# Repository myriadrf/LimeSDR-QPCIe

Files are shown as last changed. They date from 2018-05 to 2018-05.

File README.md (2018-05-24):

# LimeSDR-QPCIe 

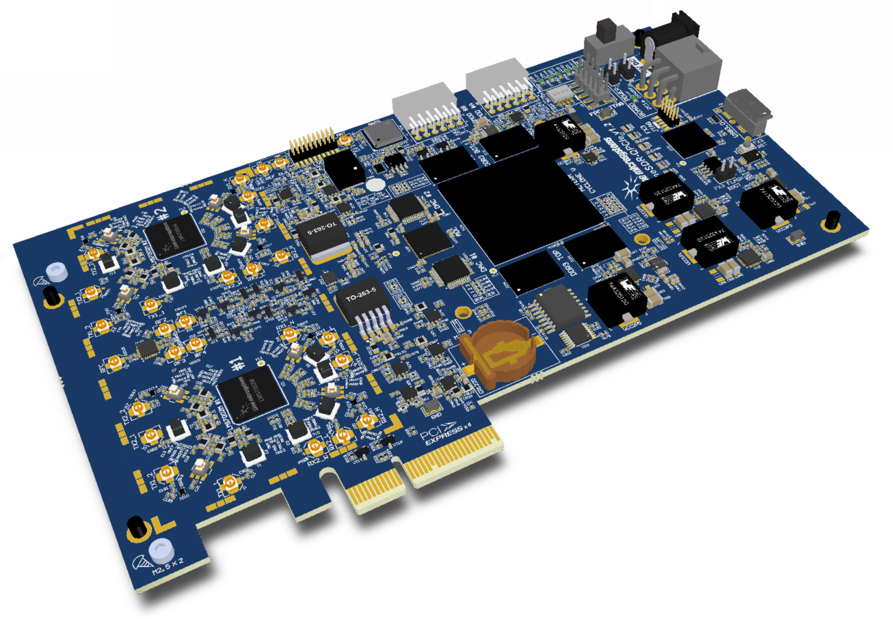
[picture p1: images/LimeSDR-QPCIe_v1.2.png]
LimeSDR-Mini board


The [LimeSDR-QPCIe ](https://wiki.myriadrf.org/LimeSDR-QPCIe) board provides a hardware platform for developing and prototyping high-performance and logic-intensive digital and RF designs using Intel’s Cyclone V FPGA and Lime Microsystems transceivers.

* **FPGA Features**
  * Cyclone V, 5CGXFC7D7F31C8N device in 896-pin FBGA package
  * 150’000 logic elements
  * 6860 Kbits embedded memory
  * 312 embedded 18x18 multipliers 
  * 7 PLLs 
  * 9 Transceivers (2.5Gbps)
  * PCIe Hard IP Blocks
  * 2 Hard Memory Controllers
 
* **RF**
  * 2x LMS7002M, FPRF transceivers
  * Onboard RSSI measurement circuits
  * Onboard loopback control switches

* **DACs and ADCs**
  * 2x DAC5672A, dual, 14-bit, Digital-To-Analog converters
  * 1x ADS424, Dual-Channel, 14-bit, Analog-To-Digital converter

* **Memory Devices**
  * 4 x 2Gbit DDR3 SDRAM (128M x 16)
  * 4Mbit flash for FX3 firmware
  * 128Mbit flash for FPGA gateware
  * 2 x 128Kbit and 2 x 512Kbit EEPROMs for LMS MCU firmware, LMS MCU data
  * 1 x 128K EEPROM for FX3 or FPGA data

* **Connections**
  * microUSB3.0 (type B) connector
  * PCIe edge connector
  * Coaxial RF (U.FL) connectors
  * 2x PMOD header (0.1” pitch)
  * FPGA (0.1” pitch) and FX3 (0.05” pitch) JTAG connectors 
  * 12V DC power jack and pinheader
  * LVDS connector (0.05” pitch)
  * Fan connector (12V/5V)
  * PCIe 6-pin power connector
  * Holder for coin cell CR1220 battery

* **Clock System**
  * 30.72MHz VCTCXO (precision: ±1 ppm initial, ±4 ppm stable).
  * Possibility to lock VCTCXO to external clock using ADF4002 or tune VCTCXO by onboard DAC (AD5662)
  * Programmable clock generator for the FPGA reference clock input or LMS PLLs
  * VCTCXO clock output for external device synchronization.
  * 1x 100 MHz, 4 x 125MHz crystal oscillators for FPGA

* **Miscellaneous devices**
  * LM75 Digital temperature sensor with 2-Wire Interface.
  * DS3231 real-time clock.
  * M0578-A3 GPS/GNSS module receiver

* **Board Size 190mm x 106.7mm (7.48” x 4.20”)**

## Contents

The directory structure is as follows:

      hardware/<version>/
          Libraries/             - Component Libraries
          OutputJobs/            - Output jobs
          PCB/                   - PCB design
          Project Outputs/       - BOM, rule check reports, Gerbers, pick & place files, PDFs
          Schematics/            - Schematic diagrams

## Licensing

The hardware designs are licensed under a Creative Commons Attribution 3.0 Unported licence.

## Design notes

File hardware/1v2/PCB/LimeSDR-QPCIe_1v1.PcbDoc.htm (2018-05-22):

Reporting Options

# File in Newer Format

Date | : | 2016-11-18
Time | : | 12:06:40
Filename | : | E:\Saniok\Lime Micro\Lime PCBs\LimeSDR-QPCIe_1v0\AltiumDesigner Design files\PCB\LimeSDR-QPCIe_1v1.PcbDoc

Version | Warning
Release 17.0 | CAUTION - Component parameters added.
Release 17.0 | CAUTION - Supports of backdrilling

This file was generated by a later version of the software

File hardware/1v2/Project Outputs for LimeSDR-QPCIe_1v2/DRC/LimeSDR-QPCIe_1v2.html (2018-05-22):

Altium

# Design Rule Verification Report

Date: | | 2017-09-22
Time: | | 15:32:23
Elapsed Time: | | 00:11:34
Filename: | | E:\Saniok\Lime Micro\Lime PCBs\LimeSDR-QPCIe_1v2\AltiumDesigner Design files\PCB\LimeSDR-QPCIe_1v2.PcbDoc

Warnings: | | 15
Rule Violations: | | 0

## Summary

Warnings | Count
Unplated multi-layer pad(s) detected | 15
Total | 15

Rule Violations | Count
Matched Lengths(Tolerance=0.1mm) (InNetClass('RxPLL_CLK')) | 0
Matched Lengths(Tolerance=0.1mm) (InNetClass('TxPLL_CLK')) | 0
Width Constraint (Min=0.1mm) (Max=20mm) (Preferred=0.2mm) (All) | 0
Short-Circuit Constraint (Allowed=Yes) (InComponent('IC50') and ispad and (name='IC50-4')),(All) | 0
Component Clearance Constraint ( Horizontal Gap = -1mm, Vertical Gap = Infinite ) (InComponent('IC30')),(InComponent('IC32')) | 0
Differential Pairs Uncoupled Length using the Gap Constraints (Min=0.1mm) (Max=0.3mm) (Prefered=0.14mm) and Width Constraints (Min=0.1mm) (Max=0.5mm) (Prefered=0.2mm) (InNetClass('TX1_BB_I') or InNetClass('TX1_BB_Q')) | 0
Matched Lengths(Tolerance=0.8mm) (InNetClass('FX3_GPIF1')) | 0
Matched Lengths(Tolerance=0.8mm) (InNetClass('FX3_CTL[0..12]') or InNetClass('FX3_DQ[0..15]') or InNet('FX3_PCLK')) | 0
Matched Lengths(Tolerance=0.5mm) (InNetClass('DAC2_DATA')) | 0
Differential Pairs Uncoupled Length using the Gap Constraints (Min=0.1mm) (Max=0.3mm) (Prefered=0.2mm) and Width Constraints (Min=0.1mm) (Max=0.3mm) (Prefered=0.2mm) (InNetClass('RX_RF')) | 0
Differential Pairs Uncoupled Length using the Gap Constraints (Min=0.1mm) (Max=0.3mm) (Prefered=0.2mm) and Width Constraints (Min=0.1mm) (Max=0.3mm) (Prefered=0.2mm) (InNetClass('TX_RF')) | 0
Differential Pairs Uncoupled Length using the Gap Constraints (Min=0.1mm) (Max=0.3mm) (Prefered=0.1mm) and Width Constraints (Min=0.2mm) (Max=0.2mm) (Prefered=0.2mm) (InNetClass('FX3_DATA')) | 0
Matched Lengths(Tolerance=0.5mm) (InNetClass('LMS1_PORT2')) | 0
Matched Lengths(Tolerance=0.5mm) (InNetClass('LMS1_PORT1')) | 0
Differential Pairs Uncoupled Length using the Gap Constraints (Min=0.1mm) (Max=0.2mm) (Prefered=0.1mm) and Width Constraints (Min=0.1mm) (Max=0.5mm) (Prefered=0.1mm) (InNetClass('DDR2_1_CK') or InNetClass('DDR2_1_CK')) | 0
Modified Polygon (Allow modified: No), (Allow shelved: No) | 0
Height Constraint (Min=0mm) (Max=2.67mm) (Prefered=2.67mm) (OnBottomLayer) | 0
Component Clearance Constraint ( Horizontal Gap = 0.01mm, Vertical Gap = 0.254mm ) (All),(All) | 0
Differential Pairs Uncoupled Length using the Gap Constraints (Min=0.1mm) (Max=0.3mm) (Prefered=0.1mm) and Width Constraints (Min=0.1mm) (Max=0.6mm) (Prefered=0.2mm) (All) | 0
Height Constraint (Min=0mm) (Max=14.47mm) (Prefered=14.47mm) (OnTopLayer) | 0
Hole Size Constraint (Min=0.2mm) (Max=10mm) (All) | 0
Pads and Vias to follow the Drill pairs settings | 0
Routing Via (MinHoleWidth=0.2mm) (MaxHoleWidth=4.5mm) (PreferredHoleWidth=0.2mm) (MinWidth=0.31mm) (MaxWidth=5mm) (PreferedWidth=0.4mm) (All) | 0
Width Constraint (Min=0.1mm) (Max=5mm) (Preferred=0.2mm) (All) | 0
Power Plane Connect Rule(Relief Connect )(Expansion=0.508mm) (Conductor Width=0.254mm) (Air Gap=0.254mm) (Entries=4) (All) | 0
Un-Routed Net Constraint ( (All) ) | 0
Short-Circuit Constraint (Allowed=No) (All),(All) | 0
Clearance Constraint (Gap=0.1mm) (All),(All) | 0
Routing Layers(All) | 0
Hole To Hole Clearance (Gap=0.15mm) (All),(All) | 0
Net Antennae (Tolerance=0mm) (All) | 0
Matched Lengths(Tolerance=0.5mm) (InNetClass('DDR3_TOP_DQ[0..31]')) | 0
Matched Lengths(Tolerance=0.5mm) (InNetClass('DDR2_2_A[0..12]')) | 0
Matched Lengths(Tolerance=0.5mm) (InNetClass('DDR3_BOT_DQ[0..31]')) | 0
Matched Lengths(Tolerance=0.5mm) (InNetClass('DDR2_1_A[0..12]')) | 0
Differential Pairs Uncoupled Length using the Gap Constraints (Min=0.1mm) (Max=0.2mm) (Prefered=0.1mm) and Width Constraints (Min=0.1mm) (Max=0.4mm) (Prefered=0.1mm) (InNet('FX3_XTAL_N') or InNet('FX3_XTAL_P')) | 0
Matched Lengths(Tolerance=0.5mm) (InNetClass('DDR3_TOP_A[0..13]')) | 0
Matched Lengths(Tolerance=0.5mm) (InNetClass('DDR3_BOT_A[0..13]')) | 0
Differential Pairs Uncoupled Length using the Gap Constraints (Min=0.2mm) (Max=0.2mm) (Prefered=0.2mm) and Width Constraints (Min=0.2mm) (Max=0.5mm) (Prefered=0.3mm) (InNetClass('PCIE') and (OnTopLayer or OnBottomLayer)) | 0
Matched Lengths(Tolerance=0.5mm) (InNetClass('DAC1_DATA')) | 0
Matched Lengths(Tolerance=0.5mm) (InNetClass('LMS2_PORT1')) | 0
Matched Lengths(Tolerance=0.5mm) (InNetClass('LMS2_PORT2')) | 0
Component Clearance Constraint ( Horizontal Gap = -1mm, Vertical Gap = Infinite ) (InComponent('R372') or InComponent('R374') or InComponent('R368') or InComponent('R364') or InComponent('R379') or InComponent('R384')),(InComponent('R372') or InComponent('R374') or InComponent('R368') or InComponent('R364') or InComponent('R379') or InComponent('R384')) | 0
Height Constraint (Min=0mm) (Max=30mm) (Prefered=14.47mm) (InComponent('FAN1') or HasFootprint('PCIe_bracket')) | 0
Component Clearance Constraint ( Horizontal Gap = -1mm, Vertical Gap = Infinite ) (HasFootprint('PCIE_BRACKET')),(HasFootprint('PCIe_bracket_screw_M2.5')) | 0
Total | 0

## Warnings

Unplated multi-layer pad(s) detected

Pad Free-0(121.375mm,111.175mm) on MultiLayer on Net GND

Pad Free-0(123.775mm,111.175mm) on MultiLayer on Net GND

Pad Free-0(122.575mm,111.175mm) on MultiLayer on Net GND

Pad Free-0(93.35mm,12.8mm) on MultiLayer on Net GND

Pad Free-0(94.55mm,12.8mm) on MultiLayer on Net GND

Pad Free-0(95.75mm,12.8mm) on MultiLayer on Net GND

Pad Free-0(190.025mm,60.825mm) on MultiLayer on Net GND

Pad Free-0(190.025mm,63.225mm) on MultiLayer on Net GND

Pad Free-0(190.025mm,62.025mm) on MultiLayer on Net GND

Pad Free-0(43.975mm,111.2mm) on MultiLayer on Net GND

Pad Free-0(46.375mm,111.2mm) on MultiLayer on Net GND

Pad Free-0(45.175mm,111.2mm) on MultiLayer on Net GND

Pad Free-0(0.05mm,63.175mm) on MultiLayer on Net GND

Pad Free-0(0.05mm,60.775mm) on MultiLayer on Net GND

Pad Free-0(0.05mm,61.975mm) on MultiLayer on Net GND

Back to top

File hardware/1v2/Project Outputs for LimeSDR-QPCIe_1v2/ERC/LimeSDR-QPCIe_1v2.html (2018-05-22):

Altium

# Electrical Rule Check Report

Date: | | 2017-09-22
Time: | | 15:44:22
Filename: | | E:\Saniok\Lime Micro\Lime PCBs\LimeSDR-QPCIe_1v2\AltiumDesigner Design files\Project Outputs for LimeSDR-QPCIe_1v2\ERC\LimeSDR-QPCIe_1v2.html

Class | Document | Message
Warning | 25_Clocks_1.SchDoc | CLK_LMK_FPGA_IN contains IO Pin and Output Pin objects (Pin IC29-AB17)
Warning | 10_RSSI1.SchDoc | FPGA_SPI2_LMS1_RX1_I_MISO contains IO Pin and Output Pin objects (Pin IC29-J7)
Warning | 10_RSSI1.SchDoc | FPGA_SPI2_LMS1_RX1_Q_MISO contains IO Pin and Output Pin objects (Pin IC29-A3)
Warning | 11_RSSI2.SchDoc | FPGA_SPI2_LMS2_RX1_I_MISO contains IO Pin and Output Pin objects (Pin IC29-H15)
Warning | 11_RSSI2.SchDoc | FPGA_SPI2_LMS2_RX1_Q_MISO contains IO Pin and Output Pin objects (Pin IC29-G9)
Warning | 11_RSSI2.SchDoc | FPGA_SPI2_LMS2_RX2_I_MISO contains IO Pin and Output Pin objects (Pin IC29-C27)
Warning | 11_RSSI2.SchDoc | FPGA_SPI2_LMS2_RX2_Q_MISO contains IO Pin and Output Pin objects (Pin IC29-F6)
Warning | 20_ADC.SchDoc | Net ADC_CLKC_N has no driving source (Pin C639-1,Pin IC37-26)
Warning | 20_ADC.SchDoc | Net ADC_CLKC_P has no driving source (Pin C638-1,Pin IC37-25)
Warning | 20_ADC.SchDoc | Net ADC_CTRL1 has no driving source (Pin IC37-35,Pin R238-1,Pin R239-2)
Warning | 20_ADC.SchDoc | Net ADC_CTRL2 has no driving source (Pin IC37-36,Pin R240-1,Pin R241-2)
Warning | 20_ADC.SchDoc | Net ADC_CTRL3 has no driving source (Pin IC37-37,Pin R242-1,Pin R243-2)
Warning | 20_ADC.SchDoc | Net ADC_INA_N has no driving source (Pin IC37-30,Pin R226-1,Pin R230-1)
Warning | 20_ADC.SchDoc | Net ADC_INA_P has no driving source (Pin IC37-29,Pin R231-1,Pin R233-1)
Warning | 20_ADC.SchDoc | Net ADC_INB_N has no driving source (Pin IC37-20,Pin R211-1,Pin R215-1)
Warning | 20_ADC.SchDoc | Net ADC_INB_P has no driving source (Pin IC37-19,Pin R216-1,Pin R218-1)
Warning | 10_RSSI1.SchDoc | Net ADL1_ADJA has no driving source (Pin IC19-21,Pin R99-1,Pin R106-1)
Warning | 10_RSSI1.SchDoc | Net ADL1_ADJB has no driving source (Pin IC19-4,Pin R98-1,Pin R105-2)
Warning | 11_RSSI2.SchDoc | Net ADL2_ADJA has no driving source (Pin IC24-21,Pin R124-1,Pin R131-1)
Warning | 11_RSSI2.SchDoc | Net ADL2_ADJB has no driving source (Pin IC24-4,Pin R123-1,Pin R130-2)
Warning | 11_RSSI2.SchDoc | Net ADL3_ADJA has no driving source (Pin IC27-21,Pin R144-1,Pin R152-1)
Warning | 11_RSSI2.SchDoc | Net ADL3_ADJB has no driving source (Pin IC27-4,Pin R143-1,Pin R151-2)
Warning | 15_FPGA_misc_banks.SchDoc | Net CLK125_FPGA_REFC_N has no driving source (Pin C326-1,Pin IC29-R7)
Warning | 15_FPGA_misc_banks.SchDoc | Net CLK125_FPGA_REFC_P has no driving source (Pin C325-1,Pin IC29-R8)
Warning | 21_DAC.SchDoc | Net DAC1_CLK has no driving source (Pin IC40-17,Pin IC40-18,Pin IC40-19,Pin IC40-20,Pin IC55-3,Pin R254-2)
Warning | 21_DAC.SchDoc | Net DAC2_CLK has no driving source (Pin IC41-17,Pin IC41-18,Pin IC41-19,Pin IC41-20,Pin IC55-5,Pin R256-2)
Warning | 15_FPGA_misc_banks.SchDoc | Net EXT_GXB_CLK_IC_N has no driving source (Pin IC29-N7,Pin R184-1)
Warning | 15_FPGA_misc_banks.SchDoc | Net EXT_GXB_CLK_IC_P has no driving source (Pin IC29-P8,Pin R183-1)
Warning | 15_FPGA_misc_banks.SchDoc | Net EXT_GXB_RX6_IC_N has no driving source (Pin IC29-R1,Pin R186-1)
Warning | 15_FPGA_misc_banks.SchDoc | Net EXT_GXB_RX6_IC_P has no driving source (Pin IC29-R2,Pin R185-1)
Warning | 15_FPGA_misc_banks.SchDoc | Net EXT_GXB_RX7_IC_N has no driving source (Pin IC29-N1,Pin R188-1)
Warning | 15_FPGA_misc_banks.SchDoc | Net EXT_GXB_RX7_IC_P has no driving source (Pin IC29-N2,Pin R187-1)
Warning | 15_FPGA_misc_banks.SchDoc | Net FLASH_AS_SCLK has no driving source (Pin IC30-6,Pin IC31-9,Pin IC32-16,Pin R176-1)
Warning | 15_FPGA_misc_banks.SchDoc | Net FLASH_AS_SS has no driving source (Pin IC30-1,Pin IC31-12,Pin IC32-7,Pin R179-1)
Warning | 15_FPGA_misc_banks.SchDoc | Net FPGA_JTAG_TCK has no driving source (Pin IC29-AC7,Pin J26-1,Pin R170-1)
Warning | 15_FPGA_misc_banks.SchDoc | Net FPGA_JTAG_TDI has no driving source (Pin IC29-U7,Pin J26-9,Pin R165-2)
Warning | 15_FPGA_misc_banks.SchDoc | Net FPGA_JTAG_TMS has no driving source (Pin IC29-V7,Pin J26-5,Pin R162-2)
Warning | 15_FPGA_misc_banks.SchDoc | Net FPGA_NCONFIG has no driving source (Pin IC29-C5,Pin IC42-G3,Pin R177-2)
Warning | 22_USB3_0_device.SchDoc | Net I2C_SCL has no driving source (Pin IC47-2,Pin IC50-16,Pin IC51-6,Pin IC57-4,Pin R287-1,Pin R351-2,Pin VT17-D)
Warning | 05_LMS7002M_1_RF.SchDoc | Net LMS1_LOOPBACK_RX1H has no driving source (Pin C26-1,Pin IC12-5)
Warning | 05_LMS7002M_1_RF.SchDoc | Net LMS1_LOOPBACK_RX2H has no driving source (Pin C25-1,Pin IC16-5)
Warning | 05_LMS7002M_1_RF.SchDoc | Net LMS1_LOOPBACK_TX12 has no driving source (Pin C21-1,Pin IC10-5)
Warning | 05_LMS7002M_1_RF.SchDoc | Net LMS1_LOOPBACK_TX22 has no driving source (Pin C22-1,Pin IC14-5)
Warning | 10_RSSI1.SchDoc | Net LMS1_RX1_BB_I_DET_N has no driving source (Pin IC19-26,Pin R95-1)
Warning | 10_RSSI1.SchDoc | Net LMS1_RX1_BB_I_DET_P has no driving source (Pin IC19-25,Pin R94-1)
Warning | 10_RSSI1.SchDoc | Net LMS1_RX1_BB_Q_DET_N has no driving source (Pin IC19-31,Pin R97-1)
Warning | 10_RSSI1.SchDoc | Net LMS1_RX1_BB_Q_DET_P has no driving source (Pin IC19-32,Pin R96-1)
Warning | 06_LMS7002M_2_RF.SchDoc | Net LMS2_LOOPBACK_RX1H has no driving source (Pin C52-1,Pin IC13-5)
Warning | 06_LMS7002M_2_RF.SchDoc | Net LMS2_LOOPBACK_RX2H has no driving source (Pin C51-1,Pin IC17-5)
Warning | 06_LMS7002M_2_RF.SchDoc | Net LMS2_LOOPBACK_TX12 has no driving source (Pin C48-1,Pin IC11-5)
Warning | 06_LMS7002M_2_RF.SchDoc | Net LMS2_LOOPBACK_TX22 has no driving source (Pin C47-1,Pin IC15-5)
Warning | 11_RSSI2.SchDoc | Net LMS2_RX1_BB_I_DET_N has no driving source (Pin IC24-26,Pin R120-1)
Warning | 11_RSSI2.SchDoc | Net LMS2_RX1_BB_I_DET_P has no driving source (Pin IC24-25,Pin R119-1)
Warning | 11_RSSI2.SchDoc | Net LMS2_RX1_BB_Q_DET_N has no driving source (Pin IC24-31,Pin R122-1)
Warning | 11_RSSI2.SchDoc | Net LMS2_RX1_BB_Q_DET_P has no driving source (Pin IC24-32,Pin R121-1)
Warning | 11_RSSI2.SchDoc | Net LMS2_RX2_BB_I_DET_N has no driving source (Pin IC27-26,Pin R140-1)
Warning | 11_RSSI2.SchDoc | Net LMS2_RX2_BB_I_DET_P has no driving source (Pin IC27-25,Pin R139-1)
Warning | 11_RSSI2.SchDoc | Net LMS2_RX2_BB_Q_DET_N has no driving source (Pin IC27-31,Pin R142-1)
Warning | 11_RSSI2.SchDoc | Net LMS2_RX2_BB_Q_DET_P has no driving source (Pin IC27-32,Pin R141-1)
Warning | 15_FPGA_misc_banks.SchDoc | Net MSEL0 has no driving source (Pin IC29-T8,Pin R160-1,Pin R161-2)
Warning | 15_FPGA_misc_banks.SchDoc | Net MSEL1 has no driving source (Pin IC29-P9,Pin R163-1,Pin R164-2)
Warning | 15_FPGA_misc_banks.SchDoc | Net MSEL2 has no driving source (Pin IC29-G5,Pin R166-1,Pin R167-2)
Warning | 15_FPGA_misc_banks.SchDoc | Net MSEL3 has no driving source (Pin IC29-P7,Pin R168-1,Pin R169-2)
Warning | 15_FPGA_misc_banks.SchDoc | Net MSEL4 has no driving source (Pin IC29-M7,Pin R171-1,Pin R172-2)
Warning | 10_RSSI1.SchDoc | Net NetC225_2 has no driving source (Pin C225-2,Pin IC18-1,Pin R89-1)
Warning | 10_RSSI1.SchDoc | Net NetC226_2 has no driving source (Pin C226-2,Pin C227-1,Pin IC18-3,Pin R90-1,Pin R91-2)
Warning | 10_RSSI1.SchDoc | Net NetC228_1 has no driving source (Pin C228-1,Pin IC19-18)
Warning | 10_RSSI1.SchDoc | Net NetC236_2 has no driving source (Pin C236-2,Pin IC20-1,Pin R102-1)
Warning | 10_RSSI1.SchDoc | Net NetC240_1 has no driving source (Pin C240-1,Pin IC19-7)
Warning | 10_RSSI1.SchDoc | Net NetC243_2 has no driving source (Pin C243-2,Pin C244-1,Pin IC20-3,Pin R103-1,Pin R104-2)
Warning | 10_RSSI1.SchDoc | Net NetC250_1 has no driving source (Pin C250-1,Pin IC21-13)
Warning | 10_RSSI1.SchDoc | Net NetC251_2 has no driving source (Pin C251-2,Pin IC21-14)
Warning | 11_RSSI2.SchDoc | Net NetC270_2 has no driving source (Pin C270-2,Pin IC23-1,Pin R114-1)
Warning | 11_RSSI2.SchDoc | Net NetC271_2 has no driving source (Pin C271-2,Pin C272-1,Pin IC23-3,Pin R115-1,Pin R116-2)
Warning | 11_RSSI2.SchDoc | Net NetC273_1 has no driving source (Pin C273-1,Pin IC24-18)
Warning | 11_RSSI2.SchDoc | Net NetC281_2 has no driving source (Pin C281-2,Pin IC25-1,Pin R125-1)
Warning | 11_RSSI2.SchDoc | Net NetC285_1 has no driving source (Pin C285-1,Pin IC24-7)
Warning | 11_RSSI2.SchDoc | Net NetC288_2 has no driving source (Pin C288-2,Pin C289-1,Pin IC25-3,Pin R128-1,Pin R129-2)
Warning | 11_RSSI2.SchDoc | Net NetC294_2 has no driving source (Pin C294-2,Pin IC26-1,Pin R134-1)
Warning | 11_RSSI2.SchDoc | Net NetC295_2 has no driving source (Pin C295-2,Pin C296-1,Pin IC26-3,Pin R135-1,Pin R136-2)
Warning | 11_RSSI2.SchDoc | Net NetC297_1 has no driving source (Pin C297-1,Pin IC27-18)
Warning | 11_RSSI2.SchDoc | Net NetC305_2 has no driving source (Pin C305-2,Pin IC28-1,Pin R147-1)
Warning | 11_RSSI2.SchDoc | Net NetC309_1 has no driving source (Pin C309-1,Pin IC27-7)
Warning | 11_RSSI2.SchDoc | Net NetC312_2 has no driving source (Pin C312-2,Pin C313-1,Pin IC28-3,Pin R148-1,Pin R149-2)
Warning | 25_Clocks_1.SchDoc | Net NetC783_1 has no driving source (Pin C783-1,Pin IC52-13)
Warning | 25_Clocks_1.SchDoc | Net NetC784_2 has no driving source (Pin C784-2,Pin IC52-14)
Warning | 25_Clocks_1.SchDoc | Net NetC786_1 has no driving source (Pin C786-1,Pin IC52-28)
Warning | 25_Clocks_1.SchDoc | Net NetC790_2 has no driving source (Pin C790-2,Pin IC52-27)
Warning | 25_Clocks_1.SchDoc | Net NetC808_2 has no driving source (Pin C808-2,Pin XO4-7)
Warning | 28_BoardPowerSupply 2.SchDoc | Net NetC928_2 has no driving source (Pin C928-2,Pin FR112-2,Pin IC66-6,Pin R457-1)
Warning | 28_BoardPowerSupply 2.SchDoc | Net NetC935_2 has no driving source (Pin C935-2,Pin IC66-1,Pin R457-2,Pin R460-2,Pin R461-2)
Warning | 28_BoardPowerSupply 2.SchDoc | Net NetC941_2 has no driving source (Pin C941-2,Pin C946-2,Pin FR113-2,Pin IC68-1,Pin IC68-6,Pin IC70-1,Pin IC70-3)
Warning | 28_BoardPowerSupply 2.SchDoc | Net NetC950_2 has no driving source (Pin C950-2,Pin IC71-1,Pin IC71-6,Pin R472-1,Pin R473-1)
Warning | 29_LMS7002M_PowerSupply.SchDoc | Net NetC954_2 has no driving source (Pin C954-2,Pin FR114-2,Pin IC72-1,Pin IC72-6)
Warning | 29_LMS7002M_PowerSupply.SchDoc | Net NetC957_2 has no driving source (Pin C957-2,Pin FR115-2,Pin IC73-1,Pin IC73-6)
Warning | 29_LMS7002M_PowerSupply.SchDoc | Net NetC962_2 has no driving source (Pin C962-2,Pin FR116-2,Pin IC74-1,Pin IC74-6)
Warning | 29_LMS7002M_PowerSupply.SchDoc | Net NetC965_2 has no driving source (Pin C965-2,Pin FR117-2,Pin IC75-1,Pin IC75-6)
Warning | 29_LMS7002M_PowerSupply.SchDoc | Net NetC970_2 has no driving source (Pin C970-2,Pin FR118-2,Pin IC76-1,Pin IC76-6)
Warning | 29_LMS7002M_PowerSupply.SchDoc | Net NetC973_2 has no driving source (Pin C973-2,Pin FR119-2,Pin IC77-1,Pin IC77-6)
Warning | 29_LMS7002M_PowerSupply.SchDoc | Net NetC978_2 has no driving source (Pin C978-2,Pin FR120-2,Pin IC78-1,Pin IC78-6)
Warning | 29_LMS7002M_PowerSupply.SchDoc | Net NetC981_2 has no driving source (Pin C981-2,Pin FR121-2,Pin IC79-1,Pin IC79-6)
Warning | 29_LMS7002M_PowerSupply.SchDoc | Net NetC990_2 has no driving source (Pin C990-2,Pin FR122-2,Pin IC80-1,Pin IC80-2)
Warning | 29_LMS7002M_PowerSupply.SchDoc | Net NetC992_2 has no driving source (Pin C992-2,Pin FR123-2,Pin IC81-1,Pin IC81-2)
Warning | 10_RSSI1.SchDoc | Net NetIC19_6 has no driving source (Pin IC19-6,Pin R107-1)
Warning | 10_RSSI1.SchDoc | Net NetIC19_8 has no driving source (Pin IC19-8,Pin R100-2)
Warning | 10_RSSI1.SchDoc | Net NetIC19_17 has no driving source (Pin IC19-17,Pin R92-2)
Warning | 10_RSSI1.SchDoc | Net NetIC19_28 has no driving source (Pin IC19-28,Pin R108-1)
Warning | 10_RSSI1.SchDoc | Net NetIC21_31 has no driving source (Pin IC21-31,Pin R110-2)
Warning | 11_RSSI2.SchDoc | Net NetIC24_6 has no driving source (Pin IC24-6,Pin R132-1)
Warning | 11_RSSI2.SchDoc | Net NetIC24_8 has no driving source (Pin IC24-8,Pin R126-2)
Warning | 11_RSSI2.SchDoc | Net NetIC24_17 has no driving source (Pin IC24-17,Pin R117-2)
Warning | 11_RSSI2.SchDoc | Net NetIC24_28 has no driving source (Pin IC24-28,Pin R133-1)
Warning | 11_RSSI2.SchDoc | Net NetIC27_6 has no driving source (Pin IC27-6,Pin R150-1)
Warning | 11_RSSI2.SchDoc | Net NetIC27_8 has no driving source (Pin IC27-8,Pin R145-2)
Warning | 11_RSSI2.SchDoc | Net NetIC27_17 has no driving source (Pin IC27-17,Pin R137-2)
Warning | 11_RSSI2.SchDoc | Net NetIC27_28 has no driving source (Pin IC27-28,Pin R153-1)
Warning | 20_ADC.SchDoc | Net NetIC38_1 has no driving source (Pin IC38-1,Pin R210-1,Pin R213-2)
Warning | 20_ADC.SchDoc | Net NetIC38_6 has no driving source (Pin IC38-6,Pin R224-2,Pin R229-1)
Warning | 20_ADC.SchDoc | Net NetIC38_7 has no driving source (Pin IC38-7,Pin R225-1,Pin R228-2)
Warning | 20_ADC.SchDoc | Net NetIC38_24 has no driving source (Pin IC38-24,Pin R209-2,Pin R214-1)
Warning | 22_USB3_0_device.SchDoc | Net NetIC42_J6 has no driving source (Pin IC42-J6,Pin R292-1)
Warning | 24_Peripherals.SchDoc | Net NetIC48_3 has no driving source (Pin IC48-3,Pin J34-1,Pin L1-1)
Warning | 24_Peripherals.SchDoc | Net NetIC48_9 has no driving source (Pin IC48-9,Pin R347-1)
Warning | 25_Clocks_1.SchDoc | Net NetIC52_30 has no driving source (Pin IC52-30,Pin R375-1)
Warning | 25_Clocks_1.SchDoc | Net NetIC52_31 has no driving source (Pin IC52-31,Pin R377-2)
Warning | 25_Clocks_1.SchDoc | Net NetIC54_5 has no driving source (Pin IC54-5,Pin R400-1)
Warning | 25_Clocks_1.SchDoc | Net NetIC54_6 has no driving source (Pin IC54-6,Pin R402-1)
Warning | 25_Clocks_1.SchDoc | Net NetIC54_7 has no driving source (Pin IC54-7,Pin R404-1)
Warning | 28_BoardPowerSupply 2.SchDoc | Net NetIC66_5 has no driving source (Pin IC66-5,Pin R458-1,Pin R459-2)
Warning | 28_BoardPowerSupply 2.SchDoc | Net NetIC68_5 has no driving source (Pin IC68-5,Pin R466-1,Pin R467-2)
Warning | 28_BoardPowerSupply 2.SchDoc | Net NetIC69_5 has no driving source (Pin IC69-5,Pin R470-1,Pin R471-2)
Warning | 28_BoardPowerSupply 2.SchDoc | Net NetIC71_5 has no driving source (Pin IC71-5,Pin R475-1,Pin R476-2)
Warning | 29_LMS7002M_PowerSupply.SchDoc | Net NetIC72_5 has no driving source (Pin IC72-5,Pin R479-1,Pin R481-2)
Warning | 29_LMS7002M_PowerSupply.SchDoc | Net NetIC73_5 has no driving source (Pin IC73-5,Pin R480-1,Pin R482-2)
Warning | 29_LMS7002M_PowerSupply.SchDoc | Net NetIC74_5 has no driving source (Pin IC74-5,Pin R485-1,Pin R487-2)
Warning | 29_LMS7002M_PowerSupply.SchDoc | Net NetIC75_5 has no driving source (Pin IC75-5,Pin R486-1,Pin R488-2)
Warning | 29_LMS7002M_PowerSupply.SchDoc | Net NetIC76_5 has no driving source (Pin IC76-5,Pin R491-1,Pin R493-2)
Warning | 29_LMS7002M_PowerSupply.SchDoc | Net NetIC77_5 has no driving source (Pin IC77-5,Pin R492-1,Pin R494-2)
Warning | 29_LMS7002M_PowerSupply.SchDoc | Net NetIC78_5 has no driving source (Pin IC78-5,Pin R497-1,Pin R499-2)
Warning | 29_LMS7002M_PowerSupply.SchDoc | Net NetIC79_5 has no driving source (Pin IC79-5,Pin R498-1,Pin R500-2)
Warning | 29_LMS7002M_PowerSupply.SchDoc | Net NetIC80_5 has no driving source (Pin IC80-5,Pin R503-1,Pin R505-1)
Warning | 29_LMS7002M_PowerSupply.SchDoc | Net NetIC81_5 has no driving source (Pin IC81-5,Pin R504-1,Pin R506-1)
Warning | 15_FPGA_misc_banks.SchDoc | Net PCIE_HSO0_N has no driving source (Pin IC29-AG1,Pin P1-B15)
Warning | 15_FPGA_misc_banks.SchDoc | Net PCIE_HSO0_P has no driving source (Pin IC29-AG2,Pin P1-B14)
Warning | 15_FPGA_misc_banks.SchDoc | Net PCIE_HSO1_N has no driving source (Pin IC29-AE1,Pin P1-B20)
Warning | 15_FPGA_misc_banks.SchDoc | Net PCIE_HSO1_P has no driving source (Pin IC29-AE2,Pin P1-B19)
Warning | 15_FPGA_misc_banks.SchDoc | Net PCIE_HSO2_N has no driving source (Pin IC29-AC1,Pin P1-B24)
Warning | 15_FPGA_misc_banks.SchDoc | Net PCIE_HSO2_P has no driving source (Pin IC29-AC2,Pin P1-B23)
Warning | 15_FPGA_misc_banks.SchDoc | Net PCIE_HSO3_N has no driving source (Pin IC29-AA1,Pin P1-B28)
Warning | 15_FPGA_misc_banks.SchDoc | Net PCIE_HSO3_P has no driving source (Pin IC29-AA2,Pin P1-B27)
Warning | 23_PCIe.SchDoc | Net PCIE_REFCLK_N has no driving source (Pin IC29-W7,Pin P1-A14)
Warning | 23_PCIe.SchDoc | Net PCIE_REFCLK_P has no driving source (Pin IC29-W8,Pin P1-A13)
Warning | 09_RF_Loopback.SchDoc | Net SR_DIN has no driving source (Pin IC7-14,Pin IC9-12)
Warning | 09_RF_Loopback.SchDoc | Net SR_LATCH has no driving source (Pin IC7-12,Pin IC8-12,Pin IC9-10)
Warning | 09_RF_Loopback.SchDoc | Net SR_SCLK has no driving source (Pin IC7-11,Pin IC8-11,Pin IC9-11)
Warning | 25_Clocks_1.SchDoc | Net TCXO_DAC_VREF has no driving source (Pin C831-2,Pin C832-1,Pin IC54-2,Pin R406-1,Pin R408-1,Pin R409-1)
Warning | 25_Clocks_1.SchDoc | Net XO_VC has no driving source (Pin R390-2,Pin R395-1,Pin XO1-1,Pin XO2-1,Pin XO3-1,Pin XO4-1)

Back to top

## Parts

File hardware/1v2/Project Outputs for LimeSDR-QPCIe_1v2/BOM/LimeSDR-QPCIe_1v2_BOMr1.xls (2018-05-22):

Item # | Comment | Quantity | Designator | Footprint | Manufacturer | Manufacturer Part Number 1 | Supplier 1 | Supplier Part Number 1 | Part Description | Assembly Info
1 | CR1220 Battery Holder | 1 | BATT1 | CR1220_SMD_holder | MPD (Memory Protection Devices) | BC501SM | Digi-Key | BC501SM-ND | HOLDER COIN CELL FOR CR1220 SMD
2 | CR1220 Battery | 1 | BATT2 |  | Panasonic - BSG | CR1220 | Digi-Key | P033-ND | Lithium Battery Non-Rechargeable (Primary) 3V Coin, 12.5mm
3 | 10pF, 25V | 12 | C1, C2, C228, C240, C273, C285, C297, C309, C829, C861, C864, C895 | CAP0402 | AVX | 04023A100JAT2A | Farnell | 2332478RL | 10pF ±5% 25V Ceramic Capacitor C0G, NP0 0402 (1005 Metric)
4 | 100pF, 50V | 111 | C3, C6, C7, C10, C13, C16, C17, C20, C21, C22, C25, C26, C31, C32, C35, C36, C39, C42, C43, C44, C47, C48, C51, C52, C181, C182, C185, C188, C189, C190, C191, C192, C193, C194, C195, C196, C197, C198, C203, C204, C207, C210, C211, C212, C213, C214, C215, C216, C217, C218, C219, C220, C225, C235, C236, C238, C242, C258, C263, C264, C265, C266, C269, C270, C280, C281, C283, C287, C294, C304, C305, C307, C311, C674, C675, C676, C679, C680, C789, C799, C800, C803, C804, C805, C809, C810, C813, C814, C815, C816, C817, C826, C844, C845, C846, C849, C850, C851, C856, C934, C943, C949, C952, C959, C960, C967, C968, C975, C976, C983, C984 | CAP0402 | Yageo | CC0402JRNPO9BN101 | Digi-Key | 311-1024-1-ND | 100pF ±5% 50V C0G, NP0 Ceramic Capacitor -55°C ~ 125°C Surface Mount, MLCC 0402 (1005 Metric) 0.039" L x 0.020" W (1.00mm x 0.50mm) | NF(C225 C236 C270 C281 C294 C305 C675 C676 C679 C680 C934 C943 C949 C952 C959 C960 C967 C968 C975 C976 C983 C984)
5 | 100nF, 16V | 432 | C4, C5, C8, C9, C11, C12, C14, C15, C18, C19, C29, C30, C33, C34, C37, C38, C40, C41, C45, C46, C177, C178, C179, C180, C227, C231, C233, C234, C237, C239, C241, C244, C246, C248, C249, C250, C251, C260, C262, C268, C272, C275, C277, C279, C282, C284, C286, C289, C291, C293, C296, C299, C301, C303, C306, C308, C310, C313, C315, C317, C318, C319, C320, C321, C322, C323, C324, C325, C326, C327, C328, C329, C330, C331, C332, C333, C334, C341, C347, C353, C359, C365, C371, C377, C383, C389, C390, C391, C392, C393, C394, C395, C396, C397, C398, C399, C400, C401, C402, C403, C404, C405, C406, C407, C408, C409, C410, C411, C412, C413, C414, C415, C416, C417, C418, C419, C420, C421, C422, C423, C424, C425, C426, C427, C428, C429, C430, C431, C432, C433, C434, C435, C436, C437, C438, C439, C440, C441, C442, C443, C444, C445, C446, C447, C448, C449, C450, C451, C452, C453, C454, C455, C456, C457, C458, C459, C460, C461, C462, C463, C464, C465, C466, C467, C468, C469, C470, C471, C472, C473, C474, C475, C476, C477, C478, C479, C480, C481, C482, C483, C484, C485, C486, C487, C488, C489, C490, C491, C492, C493, C494, C495, C496, C497, C498, C499, C500, C501, C502, C503, C504, C505, C506, C507, C508, C509, C510, C511, C512, C513, C514, C515, C516, C517, C518, C519, C520, C521, C522, C523, C524, C525, C526, C527, C528, C529, C530, C531, C532, C533, C534, C535, C536, C537, C538, C539, C540, C541, C542, C543, C545, C546, C547, C548, C549, C550, C551, C552, C554, C555, C556, C563, C564, C565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 | CAP0402 | Murata Electronics | GRM155R71C104KA88D | Mouser | 81-GRM155R71C104KA88 | 0.10µF ±10% 16V Ceramic Capacitor X7R 0402 (1005 Metric) | NF(C828)
6 | 470pF, 50V | 14 | C23, C24, C27, C28, C49, C50, C53, C54, C252, C253, C254, C255, C256, C948 | CAP0402 | TDK Corporation | C1005C0G1H471J050BA | Digi-Key | 445-2656-6-ND | 470pF ±5% 50V Ceramic Capacitor C0G, NP0 0402 (1005 Metric) | NF(C948)
7 | 1uF, 6.3V | 100 | C55, C57, C59, C61, C63, C65, C66, C67, C68, C69, C70, C71, C72, C73, C74, C75, C76, C77, C80, C82, C85, C87, C88, C89, C90, C91, C92, C93, C94, C95, C96, C97, C98, C99, C100, C101, C102, C103, C104, C105, C106, C107, C108, C109, C110, C111, C112, C113, C114, C115, C116, C118, C120, C122, C124, C126, C127, C128, C129, C130, C131, C132, C133, C134, C135, C136, C137, C138, C142, C144, C146, C148, C149, C150, C151, C152, C153, C154, C155, C156, C157, C158, C159, C160, C161, C162, C163, C164, C165, C166, C167, C168, C169, C170, C171, C172, C173, C174, C175, C176 | CAP0201 | TDK Corporation | C0603X5R0J105M030BC | Digi-Key | 445-8008-1-ND | 1µF ±20% 6.3V Ceramic Capacitor X5R 0201 (0603 Metric)
8 | 1nF, 25V | 18 | C56, C58, C60, C62, C64, C79, C81, C84, C86, C117, C119, C121, C123, C125, C141, C143, C145, C147 | CAP0201 | TDK Corporation | C0603X7R1E102K030BA | Digi-Key | 445-7275-1-ND | 1000pF ±10% 25V Ceramic Capacitor X7R 0201 (0603 Metric)
9 | 1uF, 10V | 31 | C78, C83, C139, C140, C257, C340, C346, C352, C358, C364, C370, C376, C382, C388, C560, C585, C610, C635, C796, C806, C821, C831, C892, C893, C905, C919, C920, C930, C937, C969, C972 | CAP0402 | TDK | GRM155R61A105KE15J | Newark | 490-6298-2-ND | 1µF ±10% 10V Ceramic Capacitor X5R 0402 (1005 Metric)
10 | 47pF | 16 | C183, C184, C186, C187, C199, C200, C201, C202, C205, C206, C208, C209, C221, C222, C223, C224 | CAP0402 | TDK Corporation | C1005C0G1H470F050BA | Digi-Key | 445-5361-1-ND | 47pF ±1% 50V C0G, NP0 Ceramic Capacitor -55°C ~ 125°C Surface Mount, MLCC 0402 (1005 Metric) 0.039" L x 0.020" W (1.00mm x 0.50mm)
11 | 10uF, 6.3V | 40 | C226, C230, C232, C243, C245, C247, C271, C274, C276, C288, C290, C292, C295, C298, C300, C312, C314, C316, C338, C344, C350, C356, C362, C368, C374, C380, C386, C663, C672, C683, C689, C693, C698, C710, C927, C931, C932, C936, C938, C939 | CAP0603 | Yageo | CC0603MRX5R5BB106 | Digi-Key | 311-1448-2-ND | 10µF ±20% 6.3V Ceramic Capacitor X5R 0603 (1608 Metric)
12 | 10uF, 16V | 24 | C229, C278, C302, C557, C558, C582, C583, C607, C608, C632, C633, C644, C645, C648, C654, C655, C747, C788, C928, C935, C941, C946, C990, C992 | CAP0603 | Yageo | GRM188R61C106MA73D | Digi-Key | 490-7201-2-ND | 10µF ±20% 16V Ceramic Capacitor X5R 0603 (1608 Metric) | NF(C946)
13 | 22uF, 10V | 25 | C259, C646, C656, C661, C662, C670, C671, C681, C682, C687, C688, C691, C692, C696, C697, C707, C713, C715, C717, C719, C722, C985, C986, C988, C989 | CAP0603 | TDK Corporation | C1608X5R1A226M080AC | Mouser | 810-C1608X5R1A226M | 22µF ±20% 10V Ceramic Capacitor X5R 0603 (1608 Metric)
14 | 2.2uF, 16V | 26 | C261, C267, C559, C584, C609, C634, C779, C797, C801, C833, C837, C841, C842, C847, C853, C863, C874, C880, C953, C956, C961, C964, C977, C980, C987, C991 | CAP0402 | TDK Corporation | C1005X5R1C225K050BC | Digi-Key | 445-9085-6-ND | 2.2µF ±10% 16V Ceramic Capacitor X5R 0402 (1005 Metric)
15 | 220uF, 4V | 23 | C335, C336, C337, C342, C343, C348, C349, C354, C355, C360, C361, C366, C372, C378, C384, C562, C612, C886, C887, C888, C889, C890, C891 | CAP1206 | Murata Electronics North America | GRM31CR60G227ME11L | Digi-Key | 490-9774-1-ND | 220µF ±20% 4V Ceramic Capacitor X5R 1206 (3216 Metric) | NF(C888 C891)
16 | 4.7uF, 10V | 9 | C339, C345, C351, C357, C363, C369, C375, C381, C387 | CAP0603 | TDK Corporation | CGB3B1X5R1A475K055AC | Mouser | 810-CGB3B1X5R1A475KC | 4.7µF ±10% 10V Ceramic Capacitor X5R 0603 (1608 Metric)
17 | 100uF, 6.3V | 13 | C367, C373, C379, C385, C902, C903, C904, C913, C914, C915, C916, C917, C918 | CAP1206 | MURATA | GRM31CR60J107ME39L. | Farnell | 1735535 | SMD Multilayer Ceramic Capacitor, 1206 [3216 Metric], 100 µF, 6.3 V, ± 20%, X5R, GRM Series | NF(C904 C915 C918)
18 | 0.1uF | 6 | C544, C553, C561, C594, C603, C611 | CKCA43X7R1C104M100AA | TDK | CKCA43X7R1C104M100AA | Mouser | 810-CKCA43X7R1C104M | 0.10µF ±20% Isolated Capacitor 4 Array 16V X7R 1206 (3216 Metric)
19 | 0R | 4 | C637, C643, C649, C653 | CAP0402 | Yageo | RC0402JR-070RL | Digi-Key | 311-0.0JRTR-ND | RES SMD 0.0OHM JUMPER 1/16W 0402
20 | 6.8pF, 50V | 2 | C642, C652 | CAP0402 | Murata Electronics North America | GRM1555C1H6R8BA01D | Digi-Key | 490-6252-1-ND | 6.8pF ±0.1pF 50V Ceramic Capacitor C0G, NP0 0402 (1005 Metric)
21 | 13pF, 5% | 2 | C703, C704 | CAP0402 | Murata Electronics North America | GRM1555C1H130JA01D | Digi-Key | 490-5925-2-ND | 13pF ±5% 50V Ceramic Capacitor C0G, NP0 0402 (1005 Metric)
22 | 1uF, 10V | 1 | C705 | CAP0603 | KEMET | C0603C104K8RACTU | Digi-Key | 399-1095-1-ND | CAP CER 0.1UF 10V X7R 0603
23 | 10nF, 50V | 14 | C709, C721, C724, C726, C729, C730, C739, C740, C741, C742, C743, C744, C745, C746 | CAP0402 | Yageo | CC0402KRX7R9BB103 | Digi-Key | 311-1349-2-ND | 10000pF ±10% 50V Ceramic Capacitor X7R 0402 (1005 Metric)
24 | 22nF, 50V | 17 | C753, C754, C755, C756, C757, C764, C765, C872, C873, C876, C877, C878, C879, C899, C901, C911, C925 | CAP0402 | Kemet | C0402C223K5RACTU | Digi-Key | 399-7780-1-ND | 0.022µF ±10% 50V Ceramic Capacitor X7R 0402 (1005 Metric)
25 | 22pF, 50V | 7 | C768, C769, C771, C773, C774, C775, C822 | CAP0402 | Yageo | CC0402JRNPO9BN220 | Digi-Key | 311-1018-2-ND | 22pF ±5% 50V Ceramic Capacitor C0G, NP0 0402 (1005 Metric) | NF(C822)
26 | 47pF, 50V | 4 | C791, C792, C793, C794 | CAP0402 | TDK Corporation | C1005C0G1H470F050BA | Digi-Key | 445-5361-1-ND | 47pF ±1% 50V Ceramic Capacitor C0G, NP0 0402 (1005 Metric) | NF(C791 C792 C793 C794)
27 | 18nF, 16V | 1 | C808 | CAP0402 | Yageo | CC0402KRX7R7BB183 | Digi-Key | 311-1706-1-ND | 0.018µF ±10% 16V Ceramic Capacitor X7R 0402 (1005 Metric)
28 | 1nF, 50V | 3 | C819, C820, C830 | CAP0402 | Murata Electronics | GCM155R71H102KA37D | Mouser | 81-GCM155R71H102KA7D | 1000pF ±10% 50V Ceramic Capacitor X7R 0402 (1005 Metric)
29 | 470nF, 16V | 1 | C823 | CAP0402 | Yageo | CC0402ZRY5V7BB474 | Digi-Key | 311-1735-1-ND | 0.47µF -20%, +80% 16V Ceramic Capacitor Y5V (F) 0402 (1005 Metric)
30 | 68pF, 16V | 1 | C824 | CAP0402 | Wurth Electronics Inc. | 885012005030 | Digi-Key | 732-7446-1-ND | 68pF ±5% 16V Ceramic Capacitor C0G, NP0 0402 (1005 Metric)
31 | 220pF, 50V | 1 | C827 | CAP0402 | Yageo | CC0402KRX7R9BB221 | Digi-Key | 311-1035-2-ND | 220pF ±10% 50V Ceramic Capacitor X7R 0402 (1005 Metric)
32 | 10uF, 25V | 5 | C867, C868, C869, C870, C871 | CAP0603 | Murata Electronics North America | GRM188R61E106MA73D | Digi-Key | 490-7202-2-ND | 10µF ±20% 25V Ceramic Capacitor X5R 0603 (1608 Metric)
33 | 10uF, 25V | 5 | C884, C885, C900, C910, C912 | CAP0805 | Murata Electronics North America | GRM188R61E106MA73D | Digi-Key | 490-7207-1-ND | 10µF ±20% 25V Ceramic Capacitor X5R 0603 (1608 Metric)
34 | 1200pF, 50V | 4 | C896, C909, C922, C924 | CAP0402 | Kemet | C0402C122J5GACTU | Digi-Key | 399-7334-1-ND | 1200pF ±5% 50V Ceramic Capacitor C0G, NP0 0402 (1005 Metric)
35 | 68pF, 25V | 1 | C897 | CAP0402 | Kemet | CBR04C680F3GAC | Digi-Key | 399-11255-1-ND | 68pF ±1% 25V Ceramic Capacitor C0G, NP0 0402 (1005 Metric)
36 | 1500pF, 50V | 1 | C898 | CAP0402 | Samsung Electro-Mechanics America, Inc. | CL05B152KB5NNNC | Digi-Key | 1276-1521-1-ND | 1500pF ±10% 50V Ceramic Capacitor X7R 0402 (1005 Metric)
37 | 4.7pF, 50V | 2 | C908, C921 | CAP0402 | MURATA | GRM1555C1H4R7CA01D | Farnell | 2434644 | 4.7pF ±0.25pF 50V Ceramic Capacitor C0G, NP0 0402 (1005 Metric)
38 | 2.2pF | 1 | C923 | CAP0402 | Samsung Electro-Mechanics America, Inc. | CL05C2R2CB5NNNC | Digi-Key | 1276-1271-1-ND | 2.2pF ±0.25pF 50V Ceramic Capacitor C0G, NP0 0402 (1005 Metric)
39 | 4.7uF, 6.3V | 23 | C929, C942, C944, C945, C947, C950, C951, C954, C955, C957, C958, C962, C963, C965, C966, C970, C971, C973, C974, C978, C979, C981, C982 | CAP0402 | Murata Electronics North America | GRM155R60J475ME87D | Digi-Key | 490-5408-1-ND | 4.7µF ±20% 6.3V X5R Ceramic Capacitor -55°C ~ 85°C Surface Mount, MLCC 0402 (1005 Metric) 0.039" L x 0.020" W (1.00mm x 0.50mm) | NF(C947)
40 | ESD8472 | 25 | ESD1, ESD2, ESD3, ESD4, ESD5, ESD6, ESD7, ESD8, ESD9, ESD10, ESD11, ESD12, ESD13, ESD14, ESD15, ESD16, ESD17, ESD18, ESD19, ESD20, ESD21, ESD22, ESD23, ESD24, ESD25 | ESD8472_X3DFN2 | ON Semiconductor | ESD8472MUT5G | Digi-Key | ESD8472MUT5GOSCT-ND | TVS DIODE 5.3VWM 14VC X3DFN2 | NF(ESD1 ESD2 ESD7 ESD8 ESD13 ESD14 ESD17 ESD18 ESD21 ESD22 ESD23 ESD24 ESD25)
41 | SP3010-04UTG | 1 | ESD26 | SP3010-04UTG | Littelfuse Inc | SP3010-04UTG | Digi-Key | F3507TR-ND | TVS DIODE 6VWM 12.3VC UDFN
42 | Fiducial | 8 | F1, F2, F3, F4, F5, F6, F7, F8 | Fiducial
43 | 12V DC FAN | 1 | FAN1 | FAN_60mm_v3 | Sunon Fans | HA60151V4-1000U-A99 | Digi-Key | 259-1792-ND | DC Fans DC FAN 60x20mm 12VDC Sleeve WIRE
44 | Fiducial | 9 | FL1, FL2, FL3, FL4, FL5, FL6, FL7, FL8, FL9 | Fiducial_local
45 | Ferrite | 76 | FR1, FR2, FR3, FR4, FR5, FR6, FR7, FR8, FR9, FR10, FR11, FR12, FR13, FR14, FR15, FR16, FR17, FR18, FR19, FR20, FR21, FR22, FR23, FR24, FR25, FR26, FR27, FR28, FR29, FR30, FR31, FR32, FR33, FR34, FR35, FR36, FR37, FR38, FR39, FR40, FR41, FR42, FR43, FR44, FR45, FR46, FR47, FR48, FR49, FR50, FR51, FR52, FR53, FR54, FR55, FR56, FR57, FR58, FR59, FR60, FR61, FR62, FR63, FR64, FR65, FR66, FR67, FR68, FR69, FR70, FR102, FR103, FR104, FR105, FR108, FR109 | RES0201 | Taiyo Yuden | BK0603TS601-T | Digi-Key | 587-3277-1-ND | FERRITE BEAD 600 OHM 0201 1LN | NF(FR28 FR31 FR63 FR66)
46 | 600R, 2A | 45 | FR71, FR72, FR73, FR74, FR75, FR76, FR77, FR78, FR79, FR80, FR81, FR82, FR83, FR84, FR85, FR86, FR89, FR90, FR91, FR92, FR93, FR94, FR95, FR96, FR97, FR98, FR99, FR100, FR101, FR106, FR107, FR110, FR111, FR112, FR113, FR114, FR115, FR116, FR117, FR118, FR119, FR120, FR121, FR122, FR123 | RES0805 | TDK | MPZ2012S601A | Farnell | 1669753RL | FERRITE BEAD 600 OHM 0805 1LN | NF(FR90)
47 | 220R, 0.9A | 2 | FR87, FR88 | RES0402 | TDK Corporation | MPZ1005S221ET000 | Digi-Key | 445-9329-2-ND | FERRITE BEAD 220 OHM 0402 1LN
48 | LMS7002M | 2 | IC1, IC2 | LMS7002M_v4 | Lime Microsystems | LMS7002M | Lime Microsystems | LMS7002M | IC FPRF Transceiver LMS7002M; 261 pin aQFN
49 | M24128 | 3 | IC3, IC5, IC51 | 24FC512 | STMicroelectronics | M24128-DRDW8TP/K | Digi-Key | 497-15336-1-ND | IC EEPROM 128KBIT 1MHZ 8TSSOP
50 | 24FC512 | 2 | IC4, IC6 | 24FC512 | Microchip Technology | 24FC512-I/ST | Digi-Key | 24FC512-I/ST-ND | IC EEPROM 512KBIT 1MHZ 8TSSOP
51 | 74HC595 | 2 | IC7, IC8 | 74HC595BQ,115 | Nexperia USA Inc. | 74HC595BQ,115 | Digi-Key | 1727-3327-1-ND | C 8BIT SHIFT REGISTER 16-DHVQFN
52 | SN74AVC4T774 | 2 | IC9, IC49 | SN74AVC4T774 | Texas Instruments | SN74AVC4T774RSVR | Digi-Key | 296-24741-6-ND | Voltage Level Translator Bidirectional 1 Circuit 4 Channel 380Mbps 16-UQFN (2.6x1.8)
53 | SKY13323 | 8 | IC10, IC11, IC12, IC13, IC14, IC15, IC16, IC17 | SKY13323-378LF | Skyworks Solutions Inc. | SKY13323-378LF | Digi-Key | 683-1334-1-ND | IC SPDT 100MHZ-3GHZ 6-MLPD
54 | MAX11108AVB | 6 | IC18, IC20, IC23, IC25, IC26, IC28 | MAX11108AVB+T | Maxim Integrated | MAX11108AVB+T | Digi-Key | MAX11108AVB+TCT-ND | 12 Bit Analog to Digital Converter 1 Input 1 SAR 10-UTQFN (2.1x1.6)
55 | ADL5519 | 3 | IC19, IC24, IC27 | ADL5519_32LFCSP | Analog Devices Inc. | ADL5519ACPZ-R7 | Digi-Key | ADL5519ACPZ-R7CT-ND | RF IC Detector/Controller WiMax, WLAN 1MHz ~ 10GHz 32-LFCSP-VQ (5x5)
56 | LMK00101 | 2 | IC21, IC52 | LMK00101_WQFN32 | Texas Instruments | LMK00101SQE/NOPB | Digi-Key | 296-39036-1-ND | Clock Fanout Buffer (Distribution), Multiplexer, Translator IC 200MHz 32-WFQFN Exposed Pad
57 | PE42442 | 1 | IC22 | PE42442_24QFN | Peregrine Semiconductor | PE42442A-Z | Digi-Key | 1046-1096-1-ND | RF Switch IC 3G/4G SP4T 6GHz 50 Ohm 24-QFN (4x4)
58 | 5CGXFC7D7F31C8N | 1 | IC29 | ALTR-FBGA896_A-200 | Altera | 5CGXFC7D7F31C8N | Digi-Key | 544-2772-ND | IC FPGA 480 I/O 896FBGA
59 | W25Q128FVSIG | 1 | IC30 | S25FL164K_WSO8N | Winbond Electronics | W25Q128FVSIG | Digi-Key | W25Q128FVSIG-ND | IC FLASH 128MBIT 104MHZ 8SOIC | NF(IC30)
60 | TS3A5018PWR | 1 | IC31 | TS3A5018PWR | Texas Instruments | TS3A5018PWR | Digi-Key | 296-17612-1-ND | 4 Circuit IC Switch 2:1 10 Ohm 16-TSSOP
61 | S25FL128SAGMFI01 | 1 | IC32 | SOIC16_WIDE | Spansion | S25FL128SAGMFI010 | Digi-Key | 1274-1140-ND | IC FLASH 128MBIT 133MHZ 16SO
62 | AS4C128M16D3 | 4 | IC33, IC34, IC35, IC36 | AS4C128M16D3 | Alliance Memory, Inc. | AS4C128M16D3-12BCN | Digi-Key | 1450-1083-ND | IC SDRAM DDR3 128M X 16 96-FBGA
63 | ADS4246IRGCR | 1 | IC37 | TI-RGC64-7400X7400TP_V | Texas Instruments | ADS4246IRGCT | Digi-Key | 296-28772-1-ND | 14 Bit Analog to Digital Converter 2 Input 2 Pipelined 64-VQFN (9x9)
64 | ADA4930-2 | 1 | IC38 | ADA4930-2_LFCSP-24 | Analog Devices Inc. | ADA4930-2YCPZ-R7 | Digi-Key | ADA4930-2YCPZ-R7CT-ND | Differential Amplifier 2 Circuit Differential 24-LFCSP-WQ (4x4)
65 | SN65LVDS1 | 2 | IC39, IC56 | SOT23-5 | TEXAS INSTRUMENTS | SN65LVDS1DBVR | Newark | 76C0715 | DIFFERENTIAL LINE DRIVER/RECEIVER SIGNAL SOT23-5
66 | DAC5672AIPFB | 2 | IC40, IC41 | TI-PFB48_L | Texas Instruments | DAC5672AIPFB | Digi-Key | 296-22616-ND | 14 Bit Digital to Analog Converter 2 48-TQFP (7x7)
67 | CYUSB3013 | 1 | IC42 | CYUSB3013 | Cypress Semiconductor Corp | CYUSB3013-BZXC | Digi-Key | 428-3181-ND | IC ARM9 USB3 CONTROLLER 121FBGA
68 | M25P40 | 2 | IC43, IC46 | M25P40-VMN6TPB_SO8N | Micron Technology Inc | M25P40-VMN6TPB TR | Digi-Key | M25P40-VMN6TPBTR-ND | IC FLASH 4MBIT 75MHZ 8SO
69 | FXLA108 | 2 | IC44, IC45 | FXLA108 | Fairchild Semiconductor | FXLA108BQX | Digi-Key | FXLA108BQXCT-ND | Voltage Level Translator Bidirectional 1 Circuit 8 Channel 140Mbps 20-DQFN (2.5x4.5)
70 | LM75 | 1 | IC47 | HWSON8_LM75 | NXP Semiconductors | LM75BTP,147 | Digi-Key | 568-9815-2-ND | Temperature Sensor Digital, Local -55°C ~ 125°C 11 b 8-HWSON (2x3)
71 | GPS/GNSS M0578-A3 | 1 | IC48 | M10578-A3 | Antenova | M10578-A3 | Digi-Key | 627-1074-1-ND | RADIONOVA RF Receiver GPS 1.575GHz -165dBm Module
72 | DS3231S# | 1 | IC50 | DS3231S#_SOIC16_SOIC8 | MAXIM INTEGRATED PRODUCTS | DS3231S# | Farnell | 2519295 | Real Time Clock (RTC) IC Clock/Calendar I²C, 2-Wire Serial 16-SOIC (0.295", 7.50mm Width)
73 | ADF4002 | 1 | IC53 | ADF4002 | Analog Devices Inc | ADF4002BCPZ-RL7 | Digi-Key | ADF4002BCPZ-RL7CT-ND | IC PLL FREQUENCY SYNTH 20-LFCSP
74 | AD5662 | 1 | IC54 | AD5662_SOT23-8 | Analog Devices Inc. | AD5662BRJZ-2REEL7 | Digi-Key | AD5662BRJZ-2REEL7CT-ND | IC DAC 16BIT BUFF V-OUT SOT23-8
75 | LMK00105 | 1 | IC55 | LMK00105SQ | Texas Instruments | LMK00105SQ/NOPB | Digi-Key | LMK00105SQ/NOPBCT-ND | Clock Fanout Buffer (Distribution), Multiplexer, Translator IC 200MHz 24-WFQFN Exposed Pad
76 | Si5351C | 1 | IC57 | Si5351C_20QFN | Silicon Labs | SI5351C-B-GM | Digi-Key | 336-2402-ND | IC CLK GENERATOR 200MHZ 20QFN
77 | LTC4357 | 2 | IC58, IC59 | LTC4357 |  | LTC4357IDCB#TRMPBF | Digi-Key | LTC4357IDCB#TRMPBFDKR-ND | OR Controller N+1 ORing Controller N-Channel N:1 6-DFN (2x3)
78 | ADP2386 | 5 | IC60, IC61, IC62, IC63, IC64 | ADP2386 | Analog Devices Inc. | ADP2386ACPZN-R7 | Digi-Key | ADP2386ACPZN-R7DKR-ND | Buck Switching Regulator IC Positive Adjustable 0.6V 1 Output 6A 24-WFQFN Exposed Pad, CSP
79 | RT9026 | 2 | IC65, IC67 | MSOP10 | Richtek USA Inc. | RT9026GFP | Digi-Key | 1028-1010-1-ND | Converter, DDR Bus Termination Regulator Voltage Regulator IC 1 Output 10-MSOP-EP
80 | LD39100PUR | 12 | IC66, IC68, IC69, IC71, IC72, IC73, IC74, IC75, IC76, IC77, IC78, IC79 | LD39100PUR | STMicroelectronics | LD39100PUR | Digi-Key | 497-11013-1-ND | Linear Voltage Regulator IC Positive Adjustable Output 0.8 V ~ 4.5 V 1A 6-DFN (3x3)
81 | ADP150 | 1 | IC70 | SOT23-5 | Analog Devices Inc. | ADP150AUJZ-3.3-R7 | Digi-Key | ADP150AUJZ-3.3-R7CT-ND | IC REG LDO 3.3V 0.15A TSOT23-5 | NF(IC70)
82 | NCP59152 | 2 | IC80, IC81 | TO-263-5 | ON Semiconductor | NCP59152DSADJR4G | Digi-Key | NCP59152DSADJR4GOSCT-ND | Linear Voltage Regulator IC Positive Adjustable 1 Output Adj to 1.24V 1.5A D2PAK-5
83 | U.FL/MMCX | 28 | J1, J2, J3, J4, J5, J6, J7, J8, J9, J10, J11, J12, J13, J14, J15, J16, J17, J18, J19, J20, J21, J22, J23, J24, J25, J34, J35, J36 | MMCX_UFL_conn_u | Molex, LLC | 0734120110 | Digi-Key | WM5587CT-ND | Ultra Miniature Coaxial Connector Receptacle, Male Pin 50 Ohm Surface Mount Solder
84 | JTAG_10pinConnector | 1 | J26 | HEADER5x2_SM | Amphenol FCI | 54202-G0805LF | Digi-Key | 609-4723-ND | 10 Positions Header, Unshrouded Connector 0.100" (2.54mm) Surface Mount Gold or Gold, GXT
85 | Micro_USB3B | 1 | J27 | microUSB3B_SM_v2 | Amphenol Commercial Products | GSB443T33HR | Digi-Key | GSB443T33HRCT-ND | USB - micro B USB 3.1, Superspeed+ Receptacle Connector 10 Position Surface Mount, Right Angle, Horizontal
86 | Header | 3 | J28, J33, J39 | HDR_1x2 | 3M | 961102-6404-AR | Digi-Key | 3M9447-ND | 2 Positions Header, Unshrouded Connector 0.100" (2.54mm) Through Hole Gold
87 | JTAG connector | 1 | J29 | SWD_10_pin | Harwin Inc | M50-3600542 | Digi-Key | 952-1389-ND | 10 Position Header BTB Connector Gold 0.050" (1.27mm) Surface Mount
88 | Header 10x2_SM | 1 | J30 | HEADER_10x2_SM_HALF_PITCH | Amphenol FCI | 20021121-00020C4LF | Digi-Key | 609-3698-1-ND | 20 Positions Header Connector 0.050" (1.27mm) Surface Mount Gold
89 | PMOD connector | 2 | J31, J32 | PMODconn_right_angle_TH | Sullins Connector Solutions | PPPC062LJBN-RC | Digi-Key | S5559-ND | 12 Position Header Connector 0.100" (2.54mm) Through Hole, Right Angle Gold
90 | CONN_PWR_JACK_2.1x5.5mm | 1 | J37 | CONN_PWR_JACK_v2 | SWITCHCRAFT | RAPC712X | Farnell | 1608726 | Power Barrel Connector Jack 2.50mm ID (0.098"), 5.50mm OD (0.217") Through Hole, Right Angle
91 | 6-pin PCIe power | 1 | J38 | PCIe_POWER_HEADER_6PIN | Molex Connector Corporation | 0455580003 | Digi-Key | WM10869-ND | 6 Positions Header, Shrouded Connector 0.165" (4.20mm) Through Hole, Right Angle Tin
92 | 47nH | 9 | L1, MN5, MN6, MN7, MN8, MN61, MN62, MN63, MN64 | RES0402 | COILCRAFT | 0402HP-47NXJLU | Farnell | 2285856 | COILCRAFT 0402HP-47NXJLU Surface Mount High Frequency Inductor, 0402HP Series, 47 nH, 420 mA, 0402 [1005 Metric], Wirewound
93 | 1µH | 2 | L2, L3 | FDVE1040_TOKO_INDUCTOR | Vishay Dale | IHLP3232DZER1R0M01 | Digi-Key | 541-1371-6-ND | 1µH Shielded Molded Inductor 18A 5.78 mOhm Max Nonstandard
94 | 2.2µH | 2 | L4, L5 | FDVE1040_TOKO_INDUCTOR | Vishay Dale | IHLP4040DZER2R2M01 | Digi-Key | 541-1299-1-ND | 2.2µH Shielded Molded Inductor 12A 9 mOhm Max Nonstandard
95 | 3.3µH | 1 | L6 | FDVE1040_TOKO_INDUCTOR | Vishay Dale | IHLP4040DZER3R3M01 | Digi-Key | 541-1298-1-ND | 3.3µH Shielded Molded Inductor 10A 14.4 mOhm Max Nonstandard
96 | LED_green | 6 | LED1, LED2, LED3, LED4, LED5, LED7 | LED-0603-GREEN | Avago Technologies US Inc. | HSMG-C190 | Digi-Key | 516-1425-2-ND | Green 572nm LED Indication - Discrete 2.2V 0603 (1608 Metric)
97 | LED_RG_SMD | 1 | LED6 | LED-2x0603 | Avago Technologies US Inc. | HSMF-C165 | Digi-Key | 516-1419-1-ND | LED GREEN/RED DIFFUSED 0603 SMD
98 | RFI Shield clip | 18 | MECH1, MECH2, MECH3, MECH4, MECH5, MECH6, MECH7, MECH8, MECH9, MECH10, MECH11, MECH12, MECH13, MECH14, MECH15, MECH16, MECH17, MECH18 | RFI_SHIELD_CLPS_MINI | HARWIN | S0971-46R | Farnell | 2361677 | RFI SHIELD CLIP MINI TIN SMD | NF(MECH1 MECH2 MECH3 MECH4 MECH5 MECH6 MECH7 MECH8 MECH9 MECH10 MECH11 MECH12 MECH13 MECH14 MECH15 MECH16 MECH17 MECH18)
99 | PCIe bracket | 1 | MECH19 | PCIe_bracket | Keystone Electronics | 9203 | Digi-Key | 36-9203-ND | BRACKET, COMPUTER, PCI,LENGTH 120mm, HOLE TO HOLE DISTANCE 85.4mm
100 | Spacer M3 | 2 | MECH20, MECH21 | PCIe_bracket_screw_M2.5 | DURATOOL | M2.56 PRA2MCS100- | Farnell | 1420030 | The M2.56 PRA2MCS100- is a M2.5 x 6mm Machine Screw, made of 18/8 stainless steel (A2 grade) with self colour finish, cross-recessed pan head Pozidriv head style. Designed according to DIN 7985 standard. Corrosion resistant under normal atmospheric conditions.
101 | Spacer M3 | 4 | MECH22, MECH23, MECH24, MECH25 |  | BOSSARD | TDYSFF-M3/10 | TME | TDYSFF-M3/10 | Screwed spacer sleeve; Int.thread: M3; 25mm; brass
102 | # pcs. | 4 | MECH26, MECH27, MECH36, MECH37 | PCB_standoff | Keystone Electronics | 24313 | Digi-Key | 24313K-ND | Hex Standoff Threaded M3 Brass 0.394" (10.00mm)
103 | Screws M3 | 8 | MECH28, MECH29, MECH30, MECH31, MECH32, MECH33, MECH34, MECH35 |  | BOSSARD | 1003755 | TME | 1003755 | Screw; M3x6; DIN:912; Head: cheese head; imbus; steel; zinc
104 | 100uH | 8 | MN1, MN2, MN3, MN4, MN57, MN58, MN59, MN60 | RES0805 | TDK Corporation | MLF2012C101KT000 | Digi-Key | 445-1071-1-ND | 100µH Shielded Multilayer Inductor 2mA 3.1 Ohm Max 0805 (2012 Metric)
105 | 0.5pF | 12 | MN11, MN13, MN29, MN30, MN43, MN45, MN67, MN69, MN85, MN86, MN99, MN101 | CAP0402 | Yageo | CC0402CRNPO9BNR50 | Digi-Key | 311-1001-1-ND | 0.50pF ±0.25pF 50V Ceramic Capacitor C0G, NP0 0402 (1005 Metric) | NF(MN11 MN13 MN43 MN45 MN67 MN69 MN99 MN101)
106 | 2pF | 12 | MN12, MN14, MN41, MN42, MN47, MN48, MN68, MN70, MN97, MN98, MN102, MN104 | CAP0402 | AVX | 04025U2R0BAT2A | Farnell | 2332536 | 2pF ±0.1pF 50V Ceramic Capacitor C0G, NP0 0402 (1005 Metric)
107 | 0uH (0R) | 8 | MN17, MN18, MN19, MN20, MN73, MN74, MN75, MN76 | RES0805 | BOURNS | CR0805-J/-000ELF | Farnell | 2008388 | RES SMD 0.0 OHM JUMPER 1/8W 0805
108 | 8.2nH, 5% | 12 | MN21, MN22, MN23, MN24, MN35, MN36, MN77, MN78, MN79, MN80, MN91, MN92 | RES0402 | COILCRAFT | 0402HP-8N2XJLU | Farnell | 2285826 | Surface Mount High Frequency Inductor, 0402HP Series, 8.2 nH, 1.5 A, 0402 [1005 Metric], Wirewound
109 | 0.8pF | 8 | MN25, MN26, MN31, MN32, MN81, MN82, MN87, MN88 | CAP0402 | Murata Electronics North America | GRM1555C1HR80BA01D | Digi-Key | 490-6269-1-ND | 0.80pF ±0.1pF 50V Ceramic Capacitor C0G, NP0 0402 (1005 Metric)
110 | 1pF | 8 | MN27, MN28, MN44, MN46, MN83, MN84, MN100, MN103 | CAP0402 | TDK Corporation | C1005C0G1H010B050BA | Digi-Key | 445-4854-6-ND | 1pF ±0.1pF 50V Ceramic Capacitor C0G, NP0 0402 (1005 Metric) | NF(MN27 MN28 MN83 MN84)
111 | 510pF | 16 | MN33, MN34, MN39, MN40, MN49, MN50, MN55, MN56, MN89, MN90, MN95, MN96, MN105, MN106, MN111, MN112 | CAP0402 | Murata Electronics North America | GRM1555C1H511JA01D | Digi-Key | 490-3237-1-ND | 510pF ±5% 50V Ceramic Capacitor C0G, NP0 0402 (1005 Metric)
112 | 1.2pF | 8 | MN37, MN38, MN53, MN54, MN93, MN94, MN109, MN110 | CAP0402 | Murata Electronics North America | GRM1555C1H1R2CA01D | Digi-Key | 490-5927-1-ND | 1.2pF ±0.25pF 50V Ceramic Capacitor C0G, NP0 0402 (1005 Metric)
113 | 10nH, 5% | 4 | MN51, MN52, MN107, MN108 | RES0402 | COILCRAFT | 0402HP-10NXJLU | Farnell | 2285830 | Surface Mount High Frequency Inductor, 0402HP Series, 10 nH, 1.3 A, 0402 [1005 Metric], Wirewound | NF(MN51 MN52 MN107 MN108)
114 | 0R | 176 | R1, R3, R4, R7, R10, R11, R14, R17, R20, R21, R23, R24, R29, R30, R31, R35, R40, R41, R45, R47, R57, R58, R63, R64, R89, R92, R93, R94, R95, R96, R97, R100, R101, R102, R108, R110, R114, R117, R118, R119, R120, R121, R122, R125, R126, R127, R133, R134, R137, R138, R139, R140, R141, R142, R145, R146, R147, R153, R156, R157, R158, R159, R160, R161, R163, R164, R166, R167, R168, R169, R171, R172, R183, R184, R185, R186, R187, R188, R190, R191, R211, R218, R220, R223, R226, R233, R234, R235, R236, R237, R239, R241, R243, R268, R269, R270, R271, R272, R273, R274, R275, R276, R277, R278, R279, R280, R281, R282, R283, R286, R287, R288, R290, R313, R316, R317, R320, R321, R322, R323, R324, R325, R326, R335, R336, R338, R339, R342, R358, R361, R365, R367, R369, R370, R373, R375, R376, R377, R378, R380, R381, R382, R383, R390, R391, R395, R411, R412, R413, R414, R415, R416, R419, R420, R421, R422, R423, R424, R438, R441, R455, R465, R468, R469, R473, R474, R477, R478, R483, R484, R489, R490, R495, R496, R501, R502 | RES0402 | Yageo | RC0402JR-070RL | Digi-Key | 311-0.0JRTR-ND | RES SMD 0.0OHM JUMPER 1/16W 0402 | NF(R93 R101 R118 R127 R138 R146 R160 R163 R167 R169 R171 R191 R223 R234 R235 R236 R237 R269 R272 R273 R276 R277 R280 R281 R283 R286 R313 R316 R317 R320 R321 R322 R324 R339 R342 R375 R378 R380 R382 R383 R414 R416 R419 R422 R423 R424 R441 R469)
115 | 10k, 1% | 82 | R2, R5, R6, R8, R9, R18, R19, R22, R25, R26, R27, R28, R37, R38, R90, R103, R105, R106, R107, R111, R112, R113, R115, R128, R130, R131, R132, R135, R148, R150, R151, R152, R162, R165, R174, R175, R177, R178, R219, R221, R222, R238, R240, R242, R294, R296, R298, R302, R305, R307, R309, R331, R332, R333, R334, R344, R352, R362, R363, R392, R396, R397, R399, R405, R409, R431, R432, R435, R443, R454, R456, R460, R461, R463, R464, R475, R479, R480, R485, R486, R493, R494 | RES0402 | Yageo | RC0402FR-0710KL | Digi-Key | 311-10.0KLRTR-ND | RES SMD 10K OHM 1% 1/16W 0402 | NF(R305 R309 R461)
116 | 49.9R, 1% | 30 | R12, R13, R15, R16, R32, R33, R34, R36, R109, R254, R256, R366, R371, R386, R393, R400, R401, R402, R403, R404, R407, R410, RA5, RA6, RA7, RA8, RA13, RA14, RA15, RA16 | RES0402 | Samsung Electro-Mechanics America, Inc. | RC1005F49R9CS | Digi-Key | 1276-3469-6-ND | RES SMD 49.9 OHM 1% 1/16W 0402
117 | 0R | 14 | R39, R49, R50, R51, R53, R54, R55, R56, R66, R67, R68, R70, R71, R72 | RES0201 | Rohm Semiconductor | MCR006YRTJ000 | Digi-Key | RHM0.0CCCT-ND | RES SMD 0.0OHM JUMPER 1/20W 0201
118 | 10R | 8 | R42, R43, R48, R52, R59, R60, R65, R69 | RES0201 | Panasonic Electronic Components | ERJ-1GEF10R0C | Digi-Key | P10.0ABCT-ND | RES SMD 10 OHM 1% 1/20W 0201
119 | 2k2, 1% | 14 | R44, R46, R61, R62, R297, R299, R300, R303, R318, R319, R348, R349, R350, R351 | RES0402 | Stackpole Electronics Inc | RMCF0402FT2K20 | Digi-Key | RMCF0402FT2K20CT-ND | RES SMD 2.2K OHM 1% 1/16W 0402
120 | 100R, 1% | 22 | R73, R74, R77, R78, R79, R80, R81, R82, R85, R86, R87, R88, R154, R155, R194, R199, R202, R207, R208, R347, R353, R355 | RES0402 | Stackpole Electronics Inc. | RMCF0402FT100R | Digi-Key | RMCF0402FT100RDKR-ND | RES SMD 100 OHM 1% 1/16W 0402
121 | 1k, 1% | 10 | R75, R76, R83, R84, R170, R388, R394, R408, R503, R504 | RES0402 | Stackpole Electronics Inc | RMCF0402FT1K00 | Digi-Key | RMCF0402FT1K00TR-ND | RES SMD 1K OHM 1% 1/16W 0402 | NF(R75 R76 R83 R84 R408)
122 | 8.2k, 1% | 14 | R91, R104, R116, R129, R136, R149, R427, R476, R481, R482, R487, R488, R497, R498 | RES0402 | Yageo | RC0402FR-078K2L | Digi-Key | 311-8.20KLRCT-ND | RES SMD 8.2K OHM 1% 1/16W 0402
123 | 6.2k, 1% | 3 | R98, R123, R143 | RES0402 | Yageo | RC0402FR-076K2L | Digi-Key | 311-6.20KLRCT-ND | ±1% 0.063W, 1/16W Chip Resistor 0402 (1005 Metric) Moisture Resistant Thick Film
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
